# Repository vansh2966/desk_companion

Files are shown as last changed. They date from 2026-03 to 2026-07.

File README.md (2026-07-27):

# desk_companion
This is a desk_companion, more like a clock, which shows date and time, weather of ur room. will change is display according to the software i am using.eg it show the song name i am playing. its fully touch screen to its easy to use.because its touch screen is fully relies on the firmware. i used esp-32. which wifi, so can gather information from the internet. used battry for backup during power shotages. 
my main motive to make this was to see date and time, as i didnt had a desk clock, but as went through ideas, i thought i can multi-use it according to my will.
i was really forwading to making something useful for me and something i can really call project. i was past the basic ardrino projects. so decided to build something that usefull for me and so that i can also learn CAD.

**SETUP INTRUSCTIONS**
1) do the soldering of everything
2) place ur display and screw it or glue it
3) glue ur microcontroller in its place
4) screw the top lid
5) connect microcontrtoller with usb to ur pc
6) open ide, paste ur code and uplaod it (downlaod necessary librarys of ur microcontroller)

main

display1

base
display
Capture
Captur

finally

i finally completed buidling it, took me lot of time to figure it out, had change the design has the chip was getting really hot, so i added a fan.
but yea after all the things, it works really well.

WhatsApp Image 2026-05-06 at 2 39 04 PM

WhatsApp Image 2026-05-06 at 2 38 47 PM

## 🛠️ Bill of Materials (BOM)

| Item | Component | Qty | Unit Price (INR) | Total (INR) | Link |
| :--- | :--- | :---: | :--- | :--- | :--- |
| 1 | Seeed Studio XIAO ESP32-S3 | 1 | 1650 | 1650 | [Link](https://www.amazon.in/dp/B0B94JZ2YF) |
| 2 | BME280 Sensor (Temp/Humid) | 1 | 450 | 450 | [Link](https://www.amazon.in/dp/B08SVZ9LJR) |
| 3 | 5mm LDR Photoresistor | 2 | 16 | 32 | [Link](https://robu.in/product/5mm-ldr-sensor-photoresistor-photo-cell-100-200k-gl5549/) |
| 4 | 2.8" SPI TFT Touch Screen | 1 | 807 | 807 | [Link](https://robu.in/product/2-8-inch-spi-touch-screen-module-tft-interface-240320/) |
| 5 | Lithium Polymer Battery | 1 | 500 | 500 | [Link](https://www.amazon.in/dp/B0FT42CFXZ) |
| 6 | 10k Ohm Resistor | 1 | 1 | 1 | [Link](https://robu.in/product/10k-ohm-0-5w-metal-film-resistor-pack-of-50/) |
| 7 | 1M Ohm Resistor | 2 | 1 | 2 | [Link](https://robu.in/product/1m-ohm-0-5w-metal-film-resistor-pack-of-50/) |
| 8 | Misc (Wires/Solder) | 1 | 500 | 500 | N/A |
| **Total** | | | | **3942** | |

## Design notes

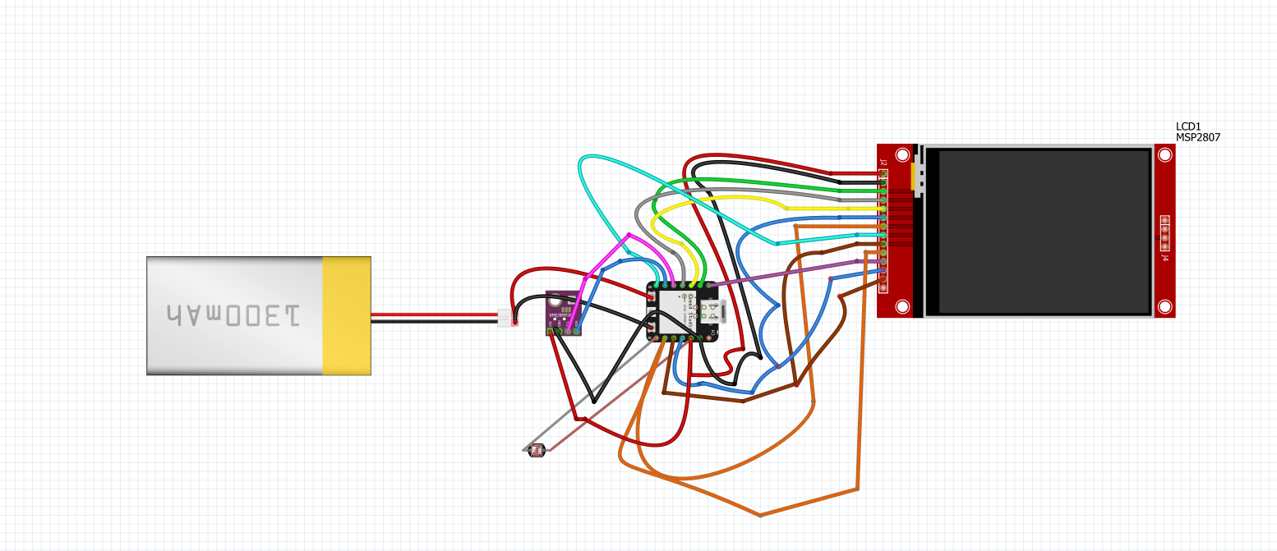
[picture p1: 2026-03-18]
circuit digram/finally.PNG

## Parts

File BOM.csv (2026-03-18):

Item |  | Quantity | Unit Price (INR) | Total (INR) | Links
1 | Seeed Studio XIAO ESP32C3 | 1 | 1650 | 1650 | https://www.amazon.in/dp/B0B94JZ2YF?psc=1&ref_=cm_sw_r_cp_ud_ct_FZNY22395XJZ99EDRYDT
2 | BME280 | 1 | 450 | 450 | https://www.amazon.in/dp/B08SVZ9LJR?psc=1&ref_=cm_sw_r_cp_ud_ct_FZNY22395XJZ99EDRYDT_1
3 | 5mm LDR Sensor Photoresistor Photo Cell | 2 | 16 | 32 | https://robu.in/product/5mm-ldr-sensor-photoresistor-photo-cell-100-200k-gl5549/
4 | 2.8 inch SPI Touch Screen Module TFT | 1 | 807 | 807 | https://robu.in/product/2-8-inch-spi-touch-screen-module-tft-interface-240320/
6 | Lithium Polymer Battery | 1 | 500 | 500 | https://www.amazon.in/dp/B0FT42CFXZ?psc=1&ref_=cm_sw_r_cp_ud_ct_FZNY22395XJZ99EDRYDT_2
7 | Misc (Wires/Solder) | 1 | 500 | 500
8 | 10k ohm resistor | 1 | 1 | 1 | https://robu.in/product/10k-ohm-0-5w-metal-film-resistor-pack-of-50/
9 | 1M ohm resistor | 1 | 1 | 2 | https://robu.in/product/1m-ohm-0-5w-metal-film-resistor-pack-of-50/
 |  |  |  | 3942

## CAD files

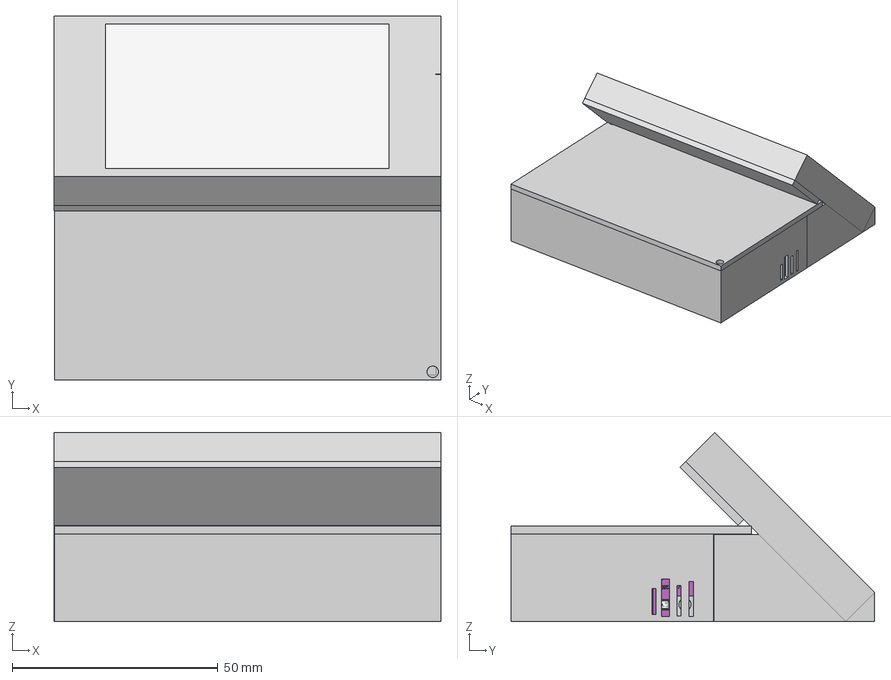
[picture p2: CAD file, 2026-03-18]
CAD step files/assembled_clock.step
94.0 x 88.3 x 46.0 mm

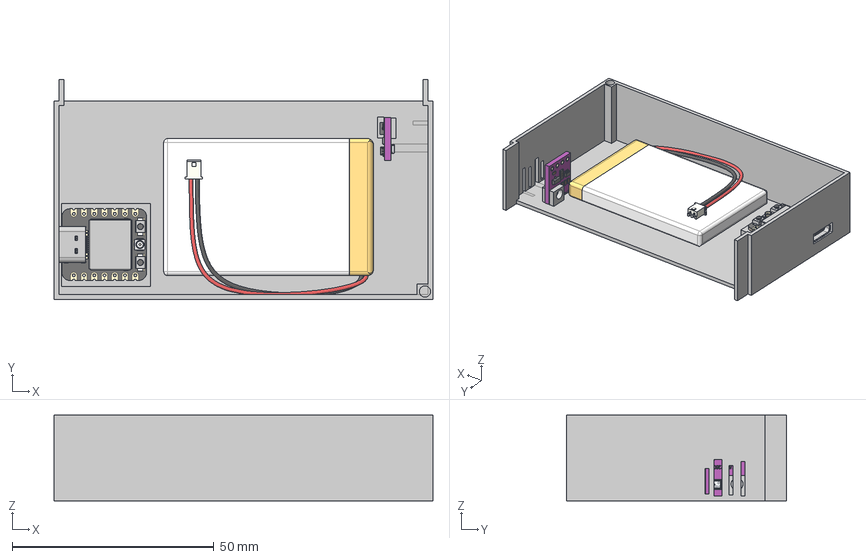
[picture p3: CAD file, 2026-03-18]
CAD step files/base.step
94.0 x 54.4 x 21.2 mm

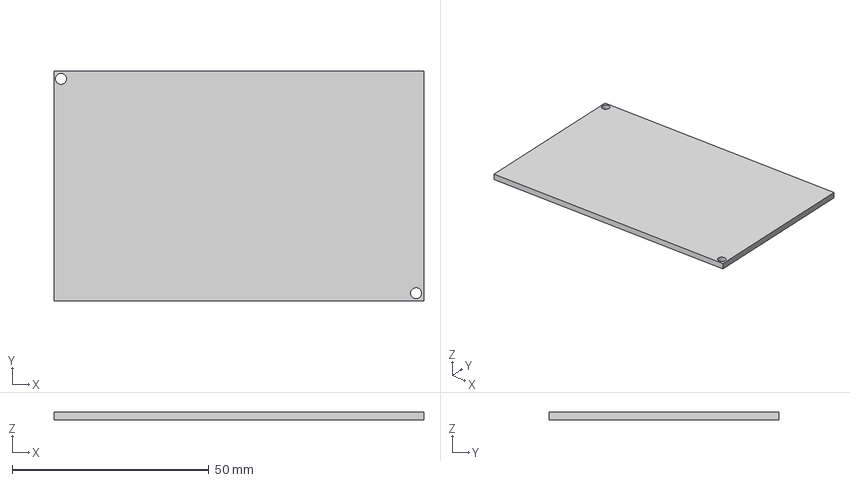
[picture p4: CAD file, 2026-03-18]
CAD step files/base_cover_back(F).step
93.9 x 58.3 x 2.00 mm

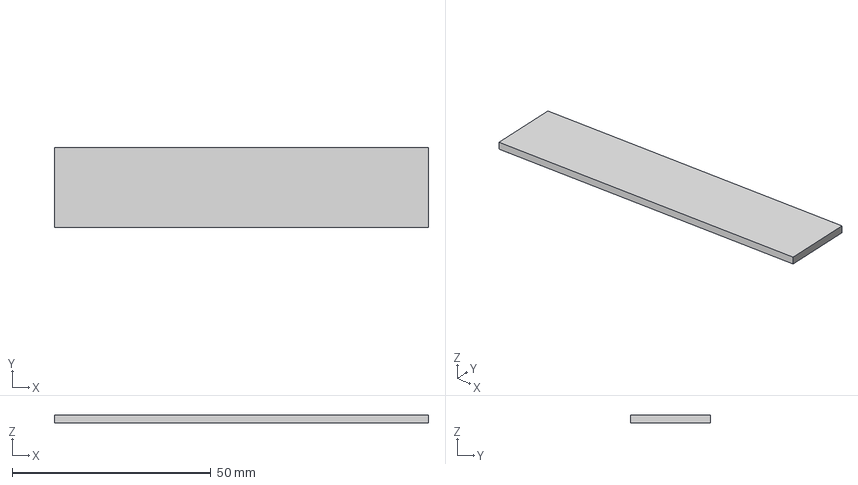
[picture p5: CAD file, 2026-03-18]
CAD step files/display_cover.step
94.0 x 20.0 x 2.00 mm

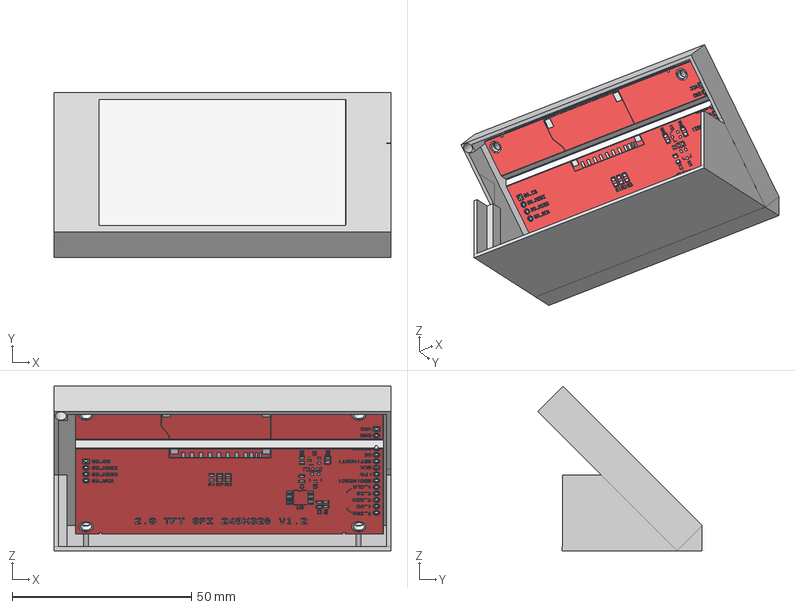
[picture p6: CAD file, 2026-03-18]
CAD step files/clock display.step
94.0 x 46.0 x 46.0 mm

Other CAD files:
CAD source files/source files/assembled_clock.iges
CAD source files/source files/base.f3d
CAD source files/source files/base_cover_back(F).f3d
CAD source files/source files/clock display.f3d
CAD source files/source files/display_cover.f3d
CAD step files/assembled_clock.stl
CAD step files/base.stl
CAD step files/base_cover_back(F).stl
CAD step files/clock display.stl
CAD step files/display_cover.stl

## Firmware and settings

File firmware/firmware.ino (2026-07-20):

#include <WiFi.h>
#include <WiFiUdp.h>
#include <time.h>
#include <SPI.h>
#include <Adafruit_GFX.h>
#include <Adafruit_ILI9341.h>
#include <XPT2046_Touchscreen.h>
#include <HTTPClient.h>
#include <WiFiClientSecure.h>
#include <ArduinoJson.h>
#include <TJpg_Decoder.h>
#include <string.h>
#include <Preferences.h>
#include <LittleFS.h>

#include <freertos/FreeRTOS.h>
#include <freertos/task.h>
#include <freertos/semphr.h>

#include <Fonts/FreeSans9pt7b.h>
#include <Fonts/FreeSans18pt7b.h>

// ==========================================
//              DEFINES & COLORS
// ==========================================
#define AESTHETIC_GOLD 0xCE40
#define SPOTIFY_GREEN  0x1EDB
#define MENU_BG        0x2104
#define UI_BG          0x0008
#define UI_PANEL       0x1084
#define UI_LINE        0x4208
#define UI_ORANGE      0xFD20
#define CANVAS_BG      0xFFFF

#define SPI_SCK  7
#define SPI_MISO 44
#define SPI_MOSI 9
#define TFT_CS   2
#define TFT_DC   4
#define TFT_RST  1
#define TFT_BL   43
#define TOUCH_CS 5

// ==========================================
//              APP STATE
// ==========================================
enum AppState { DASHBOARD, TIMER, STOPWATCH, SPOTIFY, PC_STATS, TASKS, WIFI_SCAN, WIFI_PASSWORD, WIFI_SAVED_ACTION, DRAWING, TOUCH_CALIB };
volatile AppState currentApp = DASHBOARD;
bool isMenuOpen = false;
int settingsScrollOff = 0;

enum FetchState : uint8_t { FETCH_IDLE, FETCH_SPOTIFY, FETCH_WEATHER };
volatile bool spotifyFetchPending = false;
volatile bool weatherFetchPending = false;
volatile unsigned long spotifyFetchReadyAt = 0;

// ==========================================
//              HARDWARE
// ==========================================
Adafruit_ILI9341 tft = Adafruit_ILI9341(TFT_CS, TFT_DC, TFT_RST);
XPT2046_Touchscreen touch(TOUCH_CS);
WiFiUDP telemetryUdp;
SemaphoreHandle_t dataMutex;
TaskHandle_t networkTaskHandle = NULL;
Preferences prefs;

// ==========================================
//              WIFI MANAGER STATE
// ==========================================
#define MAX_SAVED_NETWORKS 3
#define MAX_SCAN_RESULTS 10

struct SavedNetwork { char ssid[33]; char password[65]; };
SavedNetwork savedNets[MAX_SAVED_NETWORKS];
int savedNetCount = 0;

struct ScanResult { char ssid[33]; int32_t rssi; bool encrypted; };
ScanResult scanResults[MAX_SCAN_RESULTS];
int scanCount = 0;
int wifiSelIdx = -1;
char wifiPwdBuf[65] = "";
int wifiPwdLen = 0;
bool kbShift = false;
bool kbSymbol = false;
bool kbShowPwd = false;
int wifiScrollOff = 0;
bool wifiFirstBoot = false;

// ==========================================
//              TOUCH CALIBRATION
// ==========================================
int calRawMinX = 3900, calRawMaxX = 120;
int calRawMinY = 3900, calRawMaxY = 120;
int calStep = 0;
long calAccX = 0, calAccY = 0;
int calSamples = 0;

// ==========================================
//              DRAWING STATE
// ==========================================
#define CANVAS_XOFF 0
#define CANVAS_YOFF 36
#define CANVAS_W 320
#define CANVAS_H 164
#define DRAW_TB_Y 200
#define DRAW_TB_H 40

const uint16_t DRAW_COLORS[] = {
  ILI9341_BLACK, ILI9341_WHITE, 0xF800, 0x001F,
  0x07E0, 0xFFE0, UI_ORANGE, ILI9341_MAGENTA
};
#define DRAW_NCOLORS 8
const int DRAW_BRUSH_R[] = {2, 5, 10};
#define DRAW_NBRUSH 3

int drawColIdx = 0;
int drawBrushIdx = 0;
bool drawEraser = false;
bool drawMenuVisible = false;
int drawLastTX = -1, drawLastTY = -1;
uint16_t* canvasBuf = NULL;
bool canvasSaveOk = false;

// ==========================================
//              API CREDENTIALS
// ==========================================
String weatherApiKey = "028d03bd0ba9f42113631862f8ad1702";
String city = "Ahmedabad";
String countryCode = "IN";

String spotifyRefreshToken = "AQA2on0_-AbgkmolE3XrMppYDFaOGF85dztSkV8ofIkcCDEogG5VYhMXtPssBPMqmE4-fxR2WxIsRrvyMN_f6op3EBHQBUTKbLk-BEa5wuslFAPX-TLICcqNm0XH8y_eW0A";
String spotifyBase64Auth = "MWFkZDI4MGZlY2M1NGU0YWFiYWM5N2UzY2I4YTAzNmI6YjE3M2JiZTRhNzkwNGIzYmE3YzM1MDJiYTUzYThmOTE=";

String todoistToken = "aa48cfbec036a743802939b523f3c3fd95f7fa07";

// ==========================================
//              SPOTIFY STATE
// ==========================================
String spotifyAccessToken = "";
String currentSong = "Loading...";
String currentArtist = "";
String currentAlbumUrl = "";
bool isPlaying = false;

volatile bool spotifyContentDirty = true;
volatile bool spotifyControlsDirty = true;
volatile bool spotifyAlbumDirty = false;
volatile bool spotifyControlPending = false;
char spotifyControlAction[12] = "";
unsigned long lastSpotifyTokenRefresh = 0;
unsigned long lastSpotifyDataFetch = 0;

#define ALBUM_ART_MAX_SIZE 12000
static uint8_t imgBuff[ALBUM_ART_MAX_SIZE];
static uint8_t imgDownloadBuff[ALBUM_ART_MAX_SIZE];
size_t imgBuffSize = 0;
String cachedAlbumUrl = "";

// ==========================================
//              WEATHER / TELEMETRY / TASKS
// ==========================================
float currentTemp = 0.0;
int currentHumidity = 0;
String currentWeather = "--";
volatile bool weatherDirty = false;
unsigned long lastWeatherUpdate = 0;

float pcCpuUsage = 0.0;
float pcGpuTemp = -1.0;
float pcRamUsage = 0.0;
float pcWifiMbps = 0.0;
unsigned long lastTelemetryMillis = 0;
volatile bool telemetryDirty = true;

String taskItems[3] = {"Add Todoist token", "Open Tasks", "Stay focused"};
String taskIds[3] = {"", "", ""};
int taskCount = 3;
volatile bool tasksDirty = true;
volatile bool taskFetchPending = false;
volatile bool taskCompletePending = false;
String taskCompleteId = "";
unsigned long lastTaskFetch = 0;

// ==========================================
//              TIME / POWER / TIMER
// ==========================================
const char* ntpServer  = "pool.ntp.org";
const char* ntpServer2 = "time.google.com";
const char* ntpServer3 = "time.cloudflare.com";
const long  gmtOffset_sec = 19800;
const int   daylightOffset_sec = 0;
unsigned long lastNTPSync = 0;
char lastTopClock[10] = "";
int lastDashboardMinute = -1;

int currentBrightness = 155;
const int MIN_BRIGHTNESS = 20;
const int MAX_BRIGHTNESS = 230;
const int DIM_BRIGHTNESS = 28;
volatile bool screenAwake = true;
bool screenDimmed = false;
unsigned long lastInteractionMillis = 0;
unsigned long lastTouchTime = 0;

long timerSeconds = 25 * 60;
bool timerRunning = false;
unsigned long lastTimerTick = 0;
unsigned long swStartMillis = 0;
unsigned long swElapsedMillis = 0;
bool swRunning = false;

// ==========================================
//              MARQUEE
// ==========================================
GFXcanvas16* marqueeCanvas;
int marqueeX = 0;
int songPixelWidth = 0;
bool needsScrolling = false;
unsigned long lastMarqueeUpdate = 0;
unsigned long lastBeatUpdate = 0;
char marqueeSong[96] = "Loading...";

// ==========================================
//              TIMING CONSTANTS
// ==========================================
const unsigned long NTP_SYNC_INTERVAL_MS = 900000UL;
const unsigned long SPOTIFY_TOKEN_INTERVAL_MS = 3000000UL;
const unsigned long SPOTIFY_FETCH_INTERVAL_MS = 4500;
const unsigned long WEATHER_FETCH_INTERVAL_MS = 600000UL;
const unsigned long TASK_FETCH_INTERVAL_MS = 900000UL;
const unsigned long MARQUEE_INTERVAL_MS = 24;
const unsigned long BEAT_VISUALIZER_INTERVAL_MS = 90;
const unsigned long TOUCH_DEBOUNCE_MS = 45;
const unsigned long CLOCK_CHECK_INTERVAL_MS = 250;
const unsigned long STOPWATCH_DRAW_INTERVAL_MS = 100;
const unsigned long SPOTIFY_CONTROL_SETTLE_MS = 250;
const unsigned long SCREEN_DIM_TIMEOUT_MS = 30000UL;
const unsigned long SCREEN_SLEEP_TIMEOUT_MS = 120000UL;
const uint16_t API_HTTP_TIMEOUT_MS = 4500;
const uint16_t IMAGE_HTTP_TIMEOUT_MS = 7000;
const uint16_t TELEMETRY_PORT = 4210;
const unsigned long TELEMETRY_STALE_MS = 10000UL;
const int MARQUEE_X = 12;
const int MARQUEE_Y = 72;
const int MARQUEE_VIEW_WIDTH = 210;
const int MARQUEE_VIEW_HEIGHT = 35;
const int MARQUEE_GAP_PX = 48;
const int MARQUEE_TEXT_PADDING_PX = 18;

// ==========================================
//              FORWARD DECLARATIONS
// ==========================================
bool tft_output(int16_t x, int16_t y, uint16_t w, uint16_t h, uint16_t* bitmap);
static inline bool elapsedSince(unsigned long now, unsigned long last, unsigned long interval);
static inline bool timeReached(unsigned long now, unsigned long target);
void lockData();
void unlockData();
void queueFetch(FetchState fetchType, unsigned long delayMs);
void queueFetch(FetchState fetchType);
void queueSpotifyControl(const char* action);
void networkTask(void* pvParameters);
void refreshSpotifyToken();
void fetchSpotifyData();
void sendSpotifyControl(const char* action);
void fetchAlbumArtToCache(const String& url);
void fetchWeatherData();
void pollTelemetryUdp();
void fetchTodoistTasks();
void completeTodoistTask(const String& taskId);
void applyNetworkUpdates();
void controlSpotify(const char* action);
bool syncTimeNow(bool waitForSync);
void initDisplaySafely();
void setBacklight(int value);
void fadeBacklightTo(int target);
void wakeScreen();
void sleepScreen();
void updatePowerState(unsigned long now);
bool shouldKeepScreenLive();
bool readTouchPoint(int& x, int& y);
void handleTouch(int x, int y);
void drawTopBar(const char* title, uint16_t accent, bool showBack);
void updateTopClock(bool force);
void drawCenteredText(const char* text, int16_t x, int16_t y, int16_t w, int16_t h, const GFXfont* font, uint16_t color);
void fitTextToWidth(char* text, uint16_t maxWidth, const GFXfont* font);
bool hitRect(int x, int y, int rx, int ry, int rw, int rh);
void refreshTelemetryStaleUi(unsigned long now);
void redrawCurrentApp();
void redrawEntireUI();
void drawDashboardUI();
void drawStaticUI();
void drawPcStatsPreview(bool force);
void drawTasksPreview(bool force);
void updateDashboardClock(struct tm* timeinfo, bool force);
void updateDateDisplay(struct tm* timeinfo);
void updateWeatherDisplay();
void openSettingsMenu();
void closeSettingsMenu();
void drawSpotifyUI();
void drawSpotifyControls();
void drawAlbumArtPlaceholder();
void drawCachedAlbumArt();
void updateSongMetrics();
void updateSpotifyText(bool force);
void drawMarquee();
void drawBeatVisualizer(bool force);
void drawFocusAppUI();
void updateTimerDisplay();
void updateStopwatchDisplay();
void drawPcStatsUI();
void drawPcStatsValues(bool force);
void drawTasksUI();
void requestTaskComplete(int index);
void removeLocalTaskAt(int index);
// WiFi Manager
void loadSavedNetworks();
void saveSavedNetworks();
bool tryConnectSaved(bool drawUI = true);
void startWifiScan();
void drawWifiScanUI();
void drawWifiSavedActionUI();
void handleWifiSavedActionTouch(int x, int y);
void drawWifiKeyboardUI();
void drawWifiPasswordField();
void drawWifiKeyboard();
char getKeyAt(int row, int col);
void handleWifiScanTouch(int x, int y);
void handleWifiKbTouch(int x, int y);
void wifiTypeChar(char c);
void wifiBackspace();
void wifiConnect();
void onWifiConnected();
// Drawing
void initCanvasBuffer();
void drawDrawingUI();
void drawDrawingToolbar();
void drawDrawingMenuOverlay();
void canvasDrawDot(int cx, int cy, int r, uint16_t color);
void canvasDrawLine(int x0, int y0, int x1, int y1, int r, uint16_t color);
void canvasClear();
void saveDrawing(int slot);
void loadDrawing(int slot);
bool drawingSlotExists(int slot);
void handleDrawingTouch(int x, int y);
void handleDrawingDrag(int x, int y);
void handleDrawingMenuTouch(int x, int y);
// Touch Calibration
void loadCalibration();
void saveCalibration();
void drawCalibrationUI();
void handleCalibTouch();

// ==========================================
//              UTILITY FUNCTIONS
// ==========================================
bool tft_output(int16_t x, int16_t y, uint16_t w, uint16_t h, uint16_t* bitmap) {
  if (y >= tft.height()) return 0;
  tft.drawRGBBitmap(x, y, bitmap, w, h);
  return 1;
}

static inline bool elapsedSince(unsigned long now, unsigned long last, unsigned long interval) {
  return (unsigned long)(now - last) >= interval;
}

static inline bool timeReached(unsigned long now, unsigned long target) {
  return target == 0 || (long)(now - target) >= 0;
}

void drawCenteredText(const char* text, int16_t x, int16_t y, int16_t w, int16_t h, const GFXfont* font, uint16_t color) {
  tft.setFont(font);
  tft.setTextColor(color);
  int16_t x1, y1;
  uint16_t tw, th;
  tft.getTextBounds(text, 0, 0, &x1, &y1, &tw, &th);
  int16_t cx = x + (w - (int16_t)tw) / 2 - x1;
  int16_t cy = y + (h - (int16_t)th) / 2 - y1;
  tft.setCursor(cx, cy);
  tft.print(text);
}

void fitTextToWidth(char* text, uint16_t maxWidth, const GFXfont* font) {
  tft.setFont(font);
  size_t len = strlen(text);
  while (len > 0) {
    int16_t x1, y1;
    uint16_t tw, th;
    tft.getTextBounds(text, 0, 0, &x1, &y1, &tw, &th);
    if (tw <= maxWidth) return;
    text[--len] = '\0';
  }
}

bool hitRect(int x, int y, int rx, int ry, int rw, int rh) {
  const int pad = 10;
  return x >= rx - pad && x <= rx + rw + pad && y >= ry - pad && y <= ry + rh + pad;
}

void lockData() {
  if (dataMutex) xSemaphoreTake(dataMutex, portMAX_DELAY);
}

void unlockData() {
  if (dataMutex) xSemaphoreGive(dataMutex);
}

void queueFetch(FetchState fetchType, unsigned long delayMs) {
  if (fetchType == FETCH_SPOTIFY) {
    spotifyFetchPending = true;
    spotifyFetchReadyAt = (delayMs > 0) ? millis() + delayMs : 0;
  } else if (fetchType == FETCH_WEATHER) {
    weatherFetchPending = true;
  }
}
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
void loop() {
  unsigned long currentMillis = millis();

  // Touch calibration mode
  if (currentApp == TOUCH_CALIB) {
    handleCalibTouch();
    vTaskDelay(pdMS_TO_TICKS(20));
    return;
  }

  // WiFi screens don't need the standard loop logic
  if (currentApp == WIFI_SCAN || currentApp == WIFI_PASSWORD || currentApp == WIFI_SAVED_ACTION) {
    // Just handle touch
    static bool wifiTouchWasDown = false;
    bool touching = touch.touched();
    if (touching && !wifiTouchWasDown) {
      int x, y;
      if (readTouchPoint(x, y)) {
        if (currentApp == WIFI_SCAN) handleWifiScanTouch(x, y);
        else if (currentApp == WIFI_SAVED_ACTION) handleWifiSavedActionTouch(x, y);
        else handleWifiKbTouch(x, y);
      }
    }
    wifiTouchWasDown = touching;
    vTaskDelay(pdMS_TO_TICKS(10));
    return;
  }

  updatePowerState(currentMillis);
  applyNetworkUpdates();

  if (elapsedSince(currentMillis, lastNTPSync, NTP_SYNC_INTERVAL_MS)) {
    syncTimeNow(false);
  }

  static unsigned long lastTelemetryStaleCheck = 0;
  if (elapsedSince(currentMillis, lastTelemetryStaleCheck, 1000)) {
    refreshTelemetryStaleUi(currentMillis);
    lastTelemetryStaleCheck = currentMillis;
  }

  static unsigned long lastClockCheck = 0;
  if (elapsedSince(currentMillis, lastClockCheck, CLOCK_CHECK_INTERVAL_MS)) {
    struct tm timeinfo;
    if (getLocalTime(&timeinfo, 25)) {
      updateTopClock(false);
      if (currentApp == DASHBOARD && !isMenuOpen && timeinfo.tm_min != lastDashboardMinute) {
        updateDashboardClock(&timeinfo, false);
        lastDashboardMinute = timeinfo.tm_min;
      }
    }
    lastClockCheck = currentMillis;
  }

  if (currentApp == SPOTIFY && needsScrolling && screenAwake && !isMenuOpen) {
    if (elapsedSince(currentMillis, lastMarqueeUpdate, MARQUEE_INTERVAL_MS)) {
      marqueeX -= 2;
      int marqueeCycleWidth = songPixelWidth + MARQUEE_GAP_PX;
      if (marqueeX <= -marqueeCycleWidth) marqueeX = MARQUEE_VIEW_WIDTH + MARQUEE_GAP_PX;
      drawMarquee();
      lastMarqueeUpdate = currentMillis;
    }
  }

  if (currentApp == SPOTIFY && screenAwake && !isMenuOpen) {
    if (elapsedSince(currentMillis, lastBeatUpdate, BEAT_VISUALIZER_INTERVAL_MS)) {
      drawBeatVisualizer(false);
      lastBeatUpdate = currentMillis;
    }
  }

  if (timerRunning && elapsedSince(currentMillis, lastTimerTick, 1000)) {
    unsigned long elapsedSeconds = (currentMillis - lastTimerTick) / 1000;
    lastTimerTick += elapsedSeconds * 1000;
    if (elapsedSeconds >= (unsigned long)timerSeconds) {
      timerSeconds = 0;
      timerRunning = false;
    } else {
      timerSeconds -= elapsedSeconds;
    }
    if (currentApp == TIMER) updateTimerDisplay();
  }

  if (swRunning && currentApp == STOPWATCH) {
    swElapsedMillis = currentMillis - swStartMillis;
    static unsigned long lastSwDraw = 0;
    if (elapsedSince(currentMillis, lastSwDraw, STOPWATCH_DRAW_INTERVAL_MS)) {
      updateStopwatchDisplay();
      lastSwDraw = currentMillis;
    }
  }

  // Drawing: handle continuous touch drag
  if (currentApp == DRAWING && screenAwake && !drawMenuVisible) {
    bool touching = touch.touched();
    if (touching) {
      int x, y;
      if (readTouchPoint(x, y)) {
        lastInteractionMillis = currentMillis;
        if (y >= CANVAS_YOFF && y < CANVAS_YOFF + CANVAS_H) {
          handleDrawingDrag(x, y);
        }
      }
    } else {
      drawLastTX = -1;
      drawLastTY = -1;
    }
  }

  // Touch handling (tap detection for non-drawing modes)
  static bool touchWasDown = false;
  bool touching = touch.touched();
  if (currentApp != DRAWING) {
    if (touching && !touchWasDown && elapsedSince(currentMillis, lastTouchTime, TOUCH_DEBOUNCE_MS)) {
      int x, y;
      if (readTouchPoint(x, y)) {
        lastTouchTime = currentMillis;
        lastInteractionMillis = currentMillis;
        if (!screenAwake || screenDimmed) {
          wakeScreen();
        } else {
          handleTouch(x, y);
        }
      }
    }
  } else {
    // Drawing mode: handle toolbar/menu taps on press
    if (touching && !touchWasDown && elapsedSince(currentMillis, lastTouchTime, TOUCH_DEBOUNCE_MS)) {
      int x, y;
      if (readTouchPoint(x, y)) {
        lastTouchTime = currentMillis;
        lastInteractionMillis = currentMillis;
        if (!screenAwake || screenDimmed) {
          wakeScreen();
        } else if (y >= DRAW_TB_Y || y < CANVAS_YOFF || drawMenuVisible) {
          handleDrawingTouch(x, y);
        } else {
          // First dot
          handleDrawingDrag(x, y);
        }
      }
    }
  }
  touchWasDown = touching;
  if (!touching && currentApp == DRAWING) {
    drawLastTX = -1;
    drawLastTY = -1;
  }

  vTaskDelay(pdMS_TO_TICKS(2));
}

// ==========================================
//              BACKGROUND NETWORK
// ==========================================
void networkTask(void* pvParameters) {
  WiFiClientSecure secureClient;
  secureClient.setInsecure();

  for (;;) {
    unsigned long now = millis();

    if (WiFi.status() != WL_CONNECTED) {
      if (currentApp != WIFI_SCAN && currentApp != WIFI_PASSWORD && currentApp != WIFI_SAVED_ACTION) {
        if (tryConnectSaved(false)) {
          telemetryUdp.begin(TELEMETRY_PORT);
        } else {
          vTaskDelay(pdMS_TO_TICKS(5000));
        }
      } else {
        vTaskDelay(pdMS_TO_TICKS(1000));
      }
      continue;
    }
    pollTelemetryUdp();

    if (elapsedSince(now, lastSpotifyTokenRefresh, SPOTIFY_TOKEN_INTERVAL_MS)) {
      refreshSpotifyTokenWith(secureClient);
      lastSpotifyTokenRefresh = millis();
    }

    if (currentApp == SPOTIFY && elapsedSince(now, lastSpotifyDataFetch, SPOTIFY_FETCH_INTERVAL_MS)) {
      queueFetch(FETCH_SPOTIFY);
      lastSpotifyDataFetch = now;
    }

    if (elapsedSince(now, lastWeatherUpdate, WEATHER_FETCH_INTERVAL_MS)) {
      queueFetch(FETCH_WEATHER);
      lastWeatherUpdate = now;
    }

    if (todoistToken != "" && (taskFetchPending || elapsedSince(now, lastTaskFetch, TASK_FETCH_INTERVAL_MS))) {
      taskFetchPending = false;
      fetchTodoistTasksWith(secureClient);
      lastTaskFetch = millis();
    }

    if (spotifyControlPending) {
      char action[12];
      lockData();
      strncpy(action, spotifyControlAction, sizeof(action) - 1);
      action[sizeof(action) - 1] = '\0';
      spotifyControlPending = false;
      unlockData();
      sendSpotifyControlWith(secureClient, action);
      queueFetch(FETCH_SPOTIFY, SPOTIFY_CONTROL_SETTLE_MS);
    }

    if (taskCompletePending) {
      String taskId;
      lockData();
      taskId = taskCompleteId;
      taskCompleteId = "";
      taskCompletePending = false;
      unlockData();
      if (taskId != "") {
        completeTodoistTaskWith(secureClient, taskId);
        taskFetchPending = true;
      }
    }

    if (spotifyFetchPending && timeReached(now, spotifyFetchReadyAt)) {
      spotifyFetchPending = false;
      spotifyFetchReadyAt = 0;
      fetchSpotifyDataWith(secureClient);
      lastSpotifyDataFetch = millis();
    }

    if (weatherFetchPending) {
      weatherFetchPending = false;
      fetchWeatherData();
      lastWeatherUpdate = millis();
    }

    vTaskDelay(pdMS_TO_TICKS(30));
  }
}

// ==========================================
//              API FUNCTIONS
// ==========================================

// Thread-safe wrappers — each uses the task-local secureClient
void refreshSpotifyTokenWith(WiFiClientSecure& secureClient) {
  if (spotifyRefreshToken == "" || WiFi.status() != WL_CONNECTED) return;

  HTTPClient http;
  http.begin(secureClient, "https://accounts.spotify.com/api/token");
  http.setTimeout(API_HTTP_TIMEOUT_MS);
  http.useHTTP10(true);

  String authHeader;
  authHeader.reserve(6 + spotifyBase64Auth.length());
  authHeader = "Basic ";
  authHeader += spotifyBase64Auth;
  http.addHeader("Authorization", authHeader);
  http.addHeader("Content-Type", "application/x-www-form-urlencoded");

  String payload;
  payload.reserve(39 + spotifyRefreshToken.length());
  payload = "grant_type=refresh_token&refresh_token=";
  payload += spotifyRefreshToken;

  if (http.POST(payload) == 200) {
    JsonDocument doc;
    DeserializationError error = deserializeJson(doc, http.getStream());
    if (!error) {
      lockData();
      spotifyAccessToken = doc["access_token"].as<String>();
      unlockData();
    }
  }
  http.end();
}

// Keep old name for setup() calls (uses a temporary client)
void refreshSpotifyToken() {
  WiFiClientSecure sc;
  sc.setInsecure();
  refreshSpotifyTokenWith(sc);
}
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
